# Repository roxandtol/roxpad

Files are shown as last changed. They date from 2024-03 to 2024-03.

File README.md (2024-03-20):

# roxpad HE
3k keypad based on the [minipad](https://github.com/minipadKB), a Wooting style keypad, it uses the same firmware

I've designed the keypad using [KiCad](https://www.kicad.org/) for the PCB, and [OnShape](https://www.onshape.com/en/) for the case.

---
# Making it
**⚠️⚠️⚠️ This keypad is still a WIP ⚠️⚠️⚠️**

You will need:
1) The components:
    |Component|Quantity|
    |---|---|
    |[Raspberry Pi Pico](https://es.aliexpress.com/item/1005003796653297.html)|1|
    |[Lekker Switches](https://next.wooting.io/product/lekker-switch-linear60-12-pack) (you should be able to just use some modded switches aswell|3|
    |[SLSS49E Hall Effect sensor](https://www.lcsc.com/product-detail/Hall-Sensor_Slkor-SLKORMICRO-Elec-SLSS49E-3_C2904393.html)|3|
    
1) The PCB design in [The releases tab](https://github.com/roxandtol/roxpad/releases/latest)
1) The [3d design](https://www.printables.com/model/421393-roxpad-v2)
1) A soldering iron
1) 4 m3*22 screws with their nuts
1) Hot glue (for the feet)

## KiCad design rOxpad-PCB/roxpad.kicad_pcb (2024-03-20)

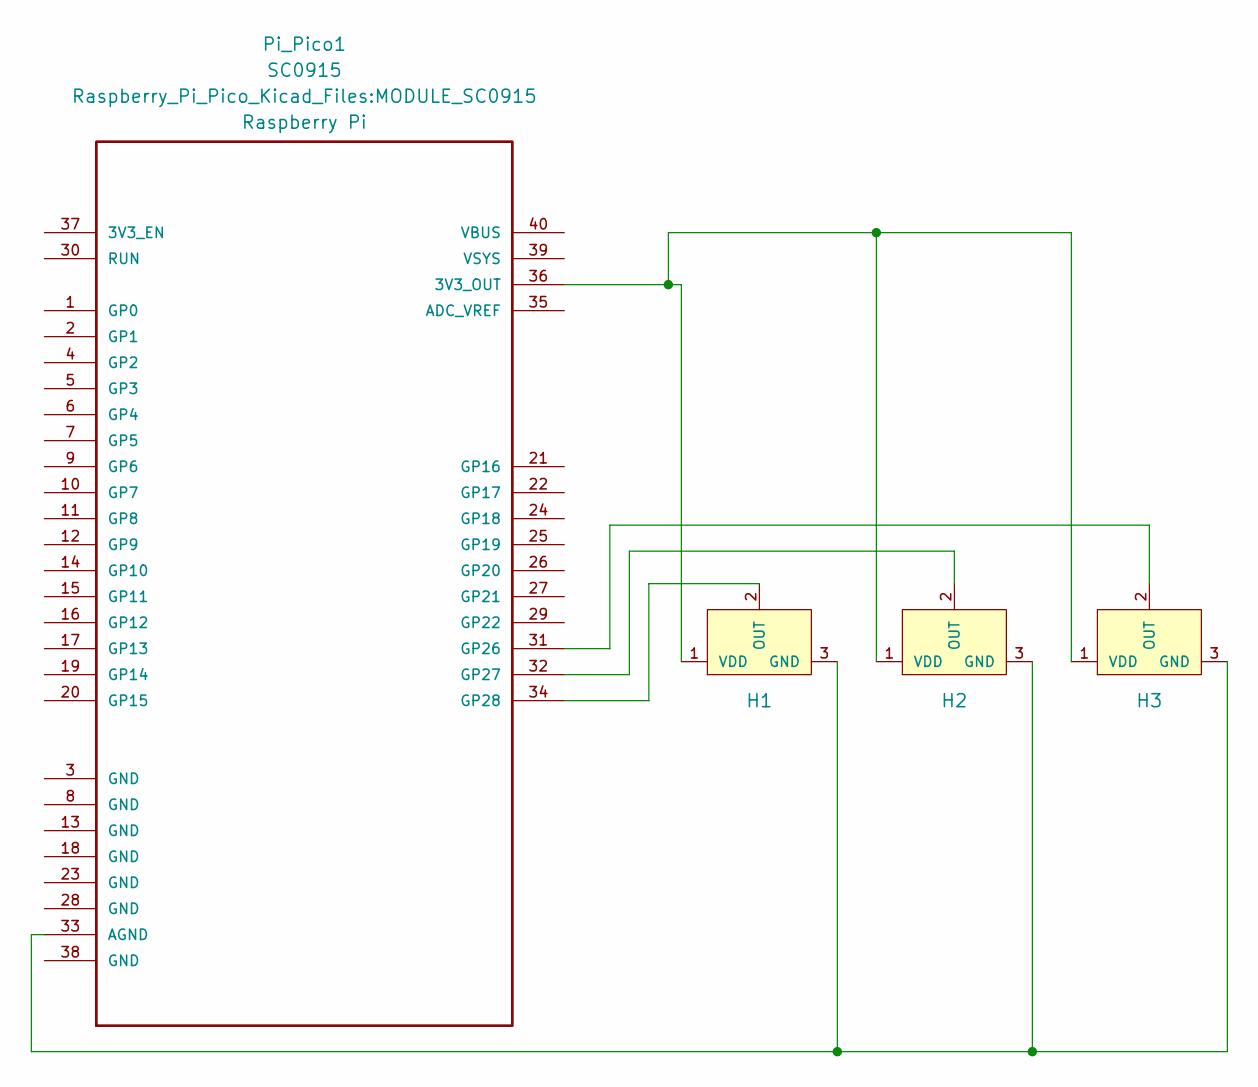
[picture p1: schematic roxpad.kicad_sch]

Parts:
H1, H2, H3: SS49E; SOT-23; MPN GH39FKSW; LCSC Part C266230
Pi_Pico1: SC0915; MODULE_SC0915; PARTREV 1.6

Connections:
unnamed: H1.3 (GND), H2.3 (GND), H3.3 (GND), Pi_Pico1.33 (AGND)
unnamed: H1.2 (OUT), Pi_Pico1.34 (GP28)
unnamed: H1.1 (VDD), H2.1 (VDD), H3.1 (VDD), Pi_Pico1.36 (3V3_OUT)
unnamed: H2.2 (OUT), Pi_Pico1.32 (GP27)
unnamed: H3.2 (OUT), Pi_Pico1.31 (GP26)

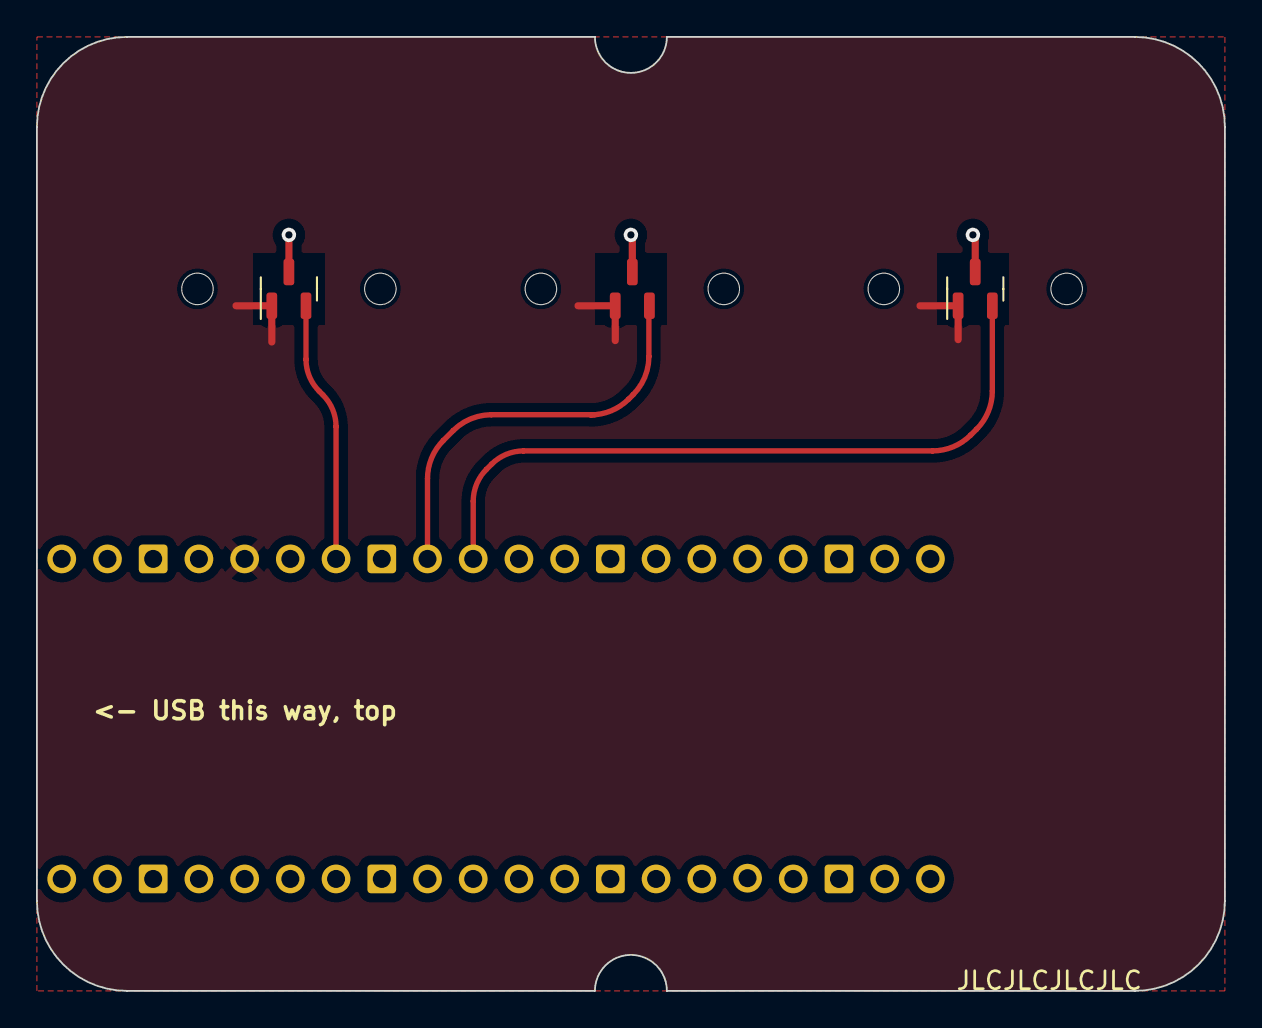
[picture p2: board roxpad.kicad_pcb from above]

Board: 2 copper layers, 66.0 x 53.0 mm, 4 parts (0 on the bottom side), 5 nets.

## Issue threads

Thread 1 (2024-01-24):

Did you get it working?

pinpox, 2024-01-24:
Hey :wave:

I'm considering building something like this. Did you get it to work?
I'm thinking about using lekker switches with the same hall effect sensor you listed, any idea if that would work well?

Just thought I'd drop a line to see if you have any experience to share :)

roxandtol, 2024-01-25:
o/
I've made some PCBs for it, but none seem to work, the voltages for each key just don't seem to work correctly, I've tried with lekker switches and with normal magnets to see if it was just the lekkers acting funny. I honestly have no idea why that happens, and i've talked with some people, and no idea either. Maybe with a redesign or something, but i've lost a bit of interest, mainly since i've put some of my own money on it for something that just doesn't seem to work. Might be bad documentation on the hall effect sensors, or the pi pico I used just trolling

roxandtol, 2024-01-25:
I can also say that the 3d designs fit the pcb completely fine, so no work is needed on those

pinpox, 2024-01-26:
Thanks for reply! I just ordered a few sensors and lekker switches to see if I can get any usable signal from them. I'll let you know if I get anything working

pinpox, 2024-03-23:
Thanks for letting me know, keep me posted!
Meanwhile I created a PCB with a similar design which I'm testing right now: https://github.com/pinpox/tm-gamepad/

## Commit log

2022-12-07 Create the project
    in Kicad
    [rOxpad.kicad_pcb, rOxpad.kicad_sch]
2022-12-07 added some libraries
    [rOxpad.kicad_pcb]
2022-12-07 design most of the base keypad schem
    [rOxpad.kicad_sch]
2022-12-07 Applied footprints!
    [rOxpad.kicad_sch]
2022-12-08 I think the pcb is done wohoo
2022-12-08 might've forgot to save whoops
    [rOxpad.kicad_pcb]
2022-12-08 started redesigning the schematic
    didn't like the result lol
    [rOxpad.kicad_pcb, rOxpad.kicad_sch]
2022-12-08 add another submodule, and continue with schem v2
    [rOxpad.kicad_sch]
2022-12-08 I think it's finished wohoo
    [rOxpad.kicad_pcb, rOxpad.kicad_sch]
2022-12-08 create gitignore and change hole size
    [rOxpad.kicad_pcb]
2022-12-08 Made some changes so it's doesn't explode
    [rOxpad.kicad_pcb, rOxpad.kicad_sch]
2022-12-08 it was a square oops
    [rOxpad.kicad_pcb]
2022-12-09 add case DXF files
    [Layer 0 - 3mm.dxf, Layer 1 - 5mm.dxf, Layer 2 - 5mm.dxf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]
2022-12-09 Fix sizing
    [rOxpad.kicad_pcb]
2022-12-09 Changed switch footprint (still same connections)
    [rOxpad.kicad_pcb, rOxpad.kicad_sch]
2022-12-09 Main board wiring finished (i hope)
    [rOxpad.kicad_pcb, rOxpad.kicad_sch]
2022-12-09 Finished all component markings
    [rOxpad.kicad_pcb]
2022-12-09 finishing touches
    [rOxpad.kicad_pcb]
2022-12-09 try new plugin
    [Layer 2 - 3mm.dxf, rOxpad.csv]
2022-12-09 change some stuff
    [rOxpad.csv, rOxpad.kicad_pcb]
2022-12-09 moved everything to a subfolder
    [BOM-rOxpad.csv, CON_BM02B-ACHSS.step, CON_MJ-4PP-9.step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]
2022-12-10 remove submodules
    going to readd them
    [CON_BM02B-ACHSS.step, CON_MJ-4PP-9.step, CON_SM02B-SRSS-TB.step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]
2022-12-11 change diode array to ESD protection circuit in readme
2022-12-14 change MCU to atmega32u2
    a lot cheaper
    [rOxpad.kicad_pcb, rOxpad.kicad_sch]
2023-03-10 start fresh
    [BOM-rOxpad.csv, Layer 0 - 3mm.dxf, Layer 1 - 5mm.dxf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]
2023-03-10 make pcb
    [roxpad.kicad_pcb, roxpad.kicad_sch]
2023-03-10 fix pinout (thanks Bexin!)
    [roxpad.kicad_pcb, roxpad.kicad_sch]
2023-03-12 update 3d print file
2023-03-13 change ' hall sensor`to proper sensor name
    [roxpad.kicad_pcb, roxpad.kicad_sch]
2023-03-13 online BOM
2023-03-13 changed designations
    [roxpad.kicad_pcb, roxpad.kicad_sch]
2023-04-17 change GND from seriees to paralel, and add support
    Sucks because I had already ordered the board, and recieved it, and soldered the pi pico. AAAAAAAAAAAAAAAAAAAAAAAAAAAAAAAAAAAAAAAAAAAAAAAAAAAAAAAAA
    [roxpad.kicad_pcb]
2023-04-23 fix keypad again and make it swag
    [roxpad.kicad_pcb]
2024-03-20 changed gnd to agnd
    I think this fixes it, won't check
    [roxpad.kicad_pcb, roxpad.kicad_sch]
